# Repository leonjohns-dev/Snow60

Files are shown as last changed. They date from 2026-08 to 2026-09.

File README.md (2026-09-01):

# Snow60

**SnowPad is a low profile 60% keyboard with choc v2 switches**

## CAD

- For the CAD, I am using Fusion 360 
- The CAD consists of a bottom case and a top plate, which are held together by 20 m2 screws and heat-inserts

| Altogether | Case |  Plate |
| --- | --- | --- |
|  |  | 

## Shematic

- The MCU used for this project is a usb-c rasberry pi pico
- This is the shematic not for a PCB rather a diagram which can be used to hand wire the board

snow60

## PCB 

- This is a PCB designed specifically for RGB lighting for each key
- It is a single PCB board with V-cuts, which allows it to be split into multiple parts for each key
- Its single purpose is to hold RGB lights for each key while reducing the cost of making a single large PCB.

| PCB | Shematic |
| --- | --- |
|   |

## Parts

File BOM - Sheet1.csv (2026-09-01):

Component | Quantity | Source | Price | Additional Notes | Links
Kailh 1353 Choc V2 | 70 | AliExpress | $28.79 |  | https://www.aliexpress.com/item/1005012840262743.html?mp=1
1N4148 Diodes | 100 | AliExpress | $2.59 |  | https://www.aliexpress.com/item/1005004103990376.html?mp=1
M2 Countersunk Screws | 30 | AliExpress | $2.89 |  | https://www.aliexpress.com/item/1005008810897680.html?mp=1
M2 Heat Inserts | 100 | AliExpress | $4.95 |  | https://www.aliexpress.com/item/1005006798286851.html?mp=1
Raspberry Pi Pico | 1 | AliExpress | $3.69 |  | https://www.aliexpress.com/item/1005006615944063.html?mp=1
0.1uf 1206 smd capacitor | 100 | AliExpress | $3.64 |  | https://www.aliexpress.com/item/4000094406197.html?mp=1
SK6812 Mini E RGB LED | 100 | AliExpress | $6.00 |  | https://www.aliexpress.com/item/1005007863635868.html?mp=1
Womier Low Profile Keycaps | 1 | Amazon | $32.35 | Includes $3.72 HST and $4.64 shipping | https://www.amazon.ca/gp/product/B0DCBWMJF5/ref=ox_sc_act_title_1?smid=AZ1RQDED92VC&th=1
3D Prints | 3 | Print-legion | $15.00 | $10 print $5 shipping said by person | https://blazecoding.xyz/ <-- Website of the person I am printing from in print-legion.
PCB | 5 | JLCPCB | $7 | Includes $2.50 shipping | Can't share jlcpcb order link
Low-profile Stabilisers | 1 | Gateron | $11.18 | Include $4.30 shipping | https://www.gateron.com/products/gateron-low-profile-plate-mounted-stabilizer?VariantsId=10540
Total: |  |  | $117.58

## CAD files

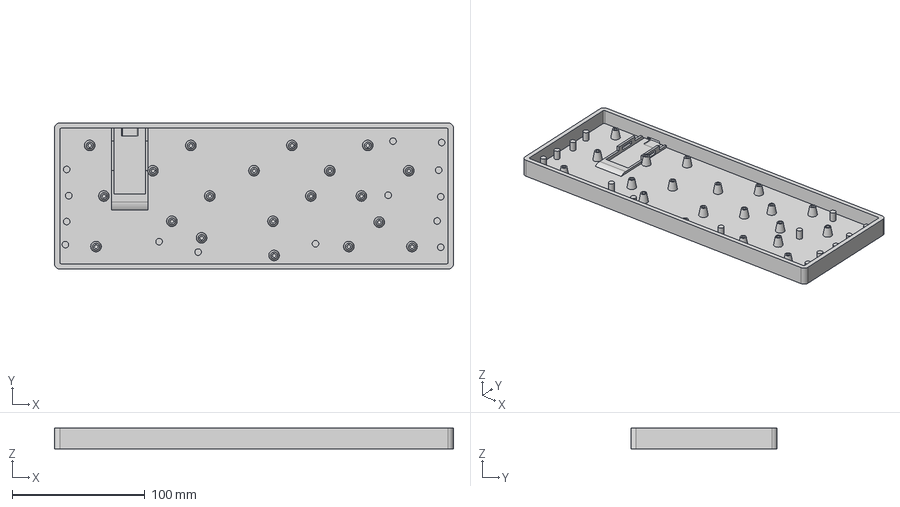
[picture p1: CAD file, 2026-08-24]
Production/snow60 case v4.step
300.7 x 110.2 x 15.5 mm

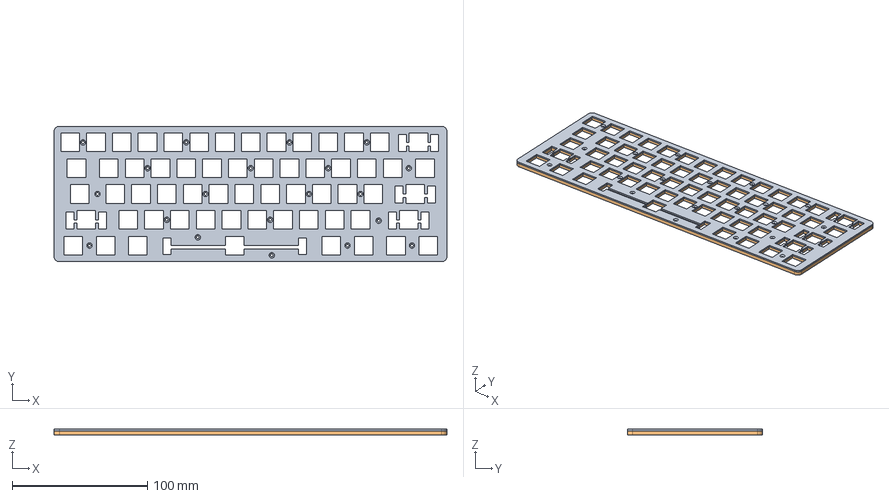
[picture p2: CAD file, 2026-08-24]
Production/plate v4.step
290.1 x 100.0 x 4.20 mm

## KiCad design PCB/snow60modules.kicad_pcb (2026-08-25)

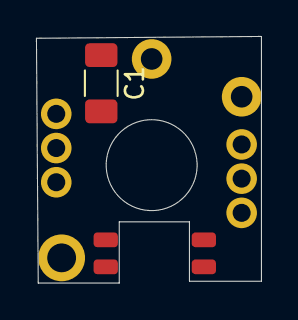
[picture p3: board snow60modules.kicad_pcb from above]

Board: 2 copper layers, 12.5 x 13.7 mm, 7 parts (0 on the bottom side), 2 nets, no tracks yet.

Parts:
C1: C; C_1206_3216Metric_Pad1.33x1.80mm_HandSolder
TP1, TP2, TP3, TP4, TP5, TP6: TestPoint

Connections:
+5V: C1.1, TP2.1 (1_1), TP5.1 (1_1)
GND: C1.2, TP1.1 (1_1), TP4.1 (1_1)

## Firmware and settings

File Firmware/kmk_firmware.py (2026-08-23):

import board
from kmk.kmk_keyboard import KMKKeyboard, DiodeOrientation
from kmk.keys import KC

keyboard = KMKKeyboard()

# 1. Hardware Pin Definitions
keyboard.row_pins = (
    board.GP16,  # Row 0
    board.GP17,  # Row 1
    board.GP18,  # Row 2
    board.GP19,  # Row 3
    board.GP20,  # Row 4
)

keyboard.col_pins = (
    board.GP15,  # Column 0
    board.GP14,  # Column 1
    board.GP13,  # Column 2
    board.GP12,  # Column 3
    board.GP11,  # Column 4
    board.GP10,  # Column 5
    board.GP09,  # Column 6
    board.GP08,  # Column 7
    board.GP07,  # Column 8
    board.GP06,  # Column 9
    board.GP05,  # Column 10
    board.GP04,  # Column 11
    board.GP03,  # Column 12
    board.GP02,  # Column 13
)

# 2. Matrix Properties
keyboard.diode_orientation = DiodeOrientation.COL2ROW

# 3. Keymap Definition (5 Rows x 14 Columns)
# Replace KC.TRNS or dummy keys below with your preferred layout keys.
# Use KC.NO for any grid intersections that don't have a physical switch installed.
keyboard.keymap = [
    [
        KC.ESC,  KC.N1,   KC.N2,   KC.N3,   KC.N4,   KC.N5,   KC.N6,   KC.N7,   KC.N8,   KC.N9,   KC.N0,   KC.MINS, KC.EQL,  KC.BSPC,
        KC.TAB,  KC.Q,    KC.W,    KC.E,    KC.R,    KC.T,    KC.Y,    KC.U,    KC.I,    KC.O,    KC.P,    KC.LBRC, KC.RBRC, KC.BSLS,
        KC.CAPS, KC.A,    KC.S,    KC.D,    KC.F,    KC.G,    KC.H,    KC.J,    KC.K,    KC.L,    KC.SCLN, KC.QUOT, KC.ENT,  KC.TRNS,
        KC.LSFT, KC.Z,    KC.X,    KC.C,    KC.V,    KC.B,    KC.N,    KC.M,    KC.COMM, KC.DOT,  KC.SLSH, KC.UP,   KC.RSFT, KC.TRNS,
        KC.LCTL, KC.LGUI, KC.LALT, KC.TRNS, KC.SPC,  KC.TRNS, KC.SPC,  KC.TRNS, KC.RALT, KC.RCTL, KC.LEFT, KC.DOWN, KC.RGHT, KC.TRNS,
    ]
]

if __name__ == '__main__':
    keyboard.go()

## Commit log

2026-08-25 Update BOM - Sheet1.csv
    [BOM - Sheet1.csv]
2026-08-27 Update BOM - Sheet1 (2).csv
    [BOM - Sheet1 (2).csv]
